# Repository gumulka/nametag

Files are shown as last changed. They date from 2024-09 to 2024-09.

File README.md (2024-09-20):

# Bluetooth ePaper Nametag

A simle project to show my name on an e-Paper

## How to build

If you are new to Zephyr, read the [Getting Started Guide](https://docs.zephyrproject.org/latest/develop/getting_started/index.html).
Afterwards you can clone and build this project with:

```bash
west init -m https://github.com/gumulka/nametag --mr main nametag
cd nametag
west update
cd epaper_nametag
```

### Bootloader

The bootloader will load and verify the image that is executed. To make it
easier to upgrade the device, two images are saved on the device and only one is
being executed, while the other is a standby for updating. The bootloader cannot
be upgraded via ble, but the image can be. Therefore making it possible to
upgrade devices in the field.

If you have a unprogrammed device, use this to build and flash the bootloader:

```bash
west build -p -b epaper_nametag -d build_mcuboot ../bootloader/mcuboot/boot/zephyr/ -- -DCONFIG_BOOT_SIGNATURE_TYPE_ECDSA_P256=y
west flash -d build_mcuboot
```

### Application

The application is different from the bootloader and is what is in need of
updates/upgrades.

```bash
west build -p -b epaper_nametag app -- -DOVERLAY_CONFIG="output.conf"
west flash
```

## Update via BLE

If you have an already running device and just want to upgrade to the latest
firmware.

Either with the nRF Connect App, which can be quite handy, or in the commandline
use these steps:

```bash
sudo mcumgr --conntype ble --connstring ctlr_name=hci0,peer_name='Nametag' image upload build/zephyr/zephyr.signed.bin
sudo mcumgr --conntype ble --connstring ctlr_name=hci0,peer_name='Nametag' image list
```

Use the second hash provided from the second command to alter the following:

```bash
sudo mcumgr --conntype ble --connstring ctlr_name=hci0,peer_name='Nametag' image test "HASH_FROM_OUTPUT"
sudo mcumgr --conntype ble --connstring ctlr_name=hci0,peer_name='Nametag' reset
# wait for the system to restart and if you are sure, that the update was successful then
sudo mcumgr  --conntype ble --connstring ctlr_name=hci0,peer_name='Nametag' image confirm "HASH_FROM_OUTPUT"
```

More information about the general procedure can be found [here](https://docs.zephyrproject.org/latest/samples/subsys/mgmt/mcumgr/smp_svr/README.html)
and [here](https://docs.zephyrproject.org/latest/services/device_mgmt/mcumgr.html)

> [!TIP]
> I have seen a few errors when trying to upload the image and found that it
> works best, if I cancel the upload command after a few seconds and restart it
> a few seconds later, basically splitting the upload into 4-5 chunks instead
> of uploading it as a whole.

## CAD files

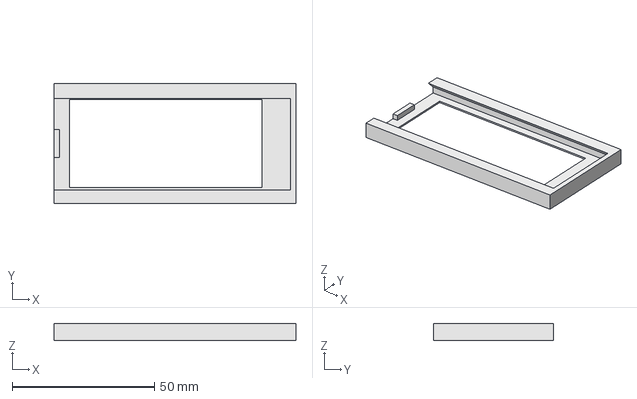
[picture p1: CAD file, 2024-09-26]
Case/Case.FCStd
85.0 x 42.0 x 6.00 mm

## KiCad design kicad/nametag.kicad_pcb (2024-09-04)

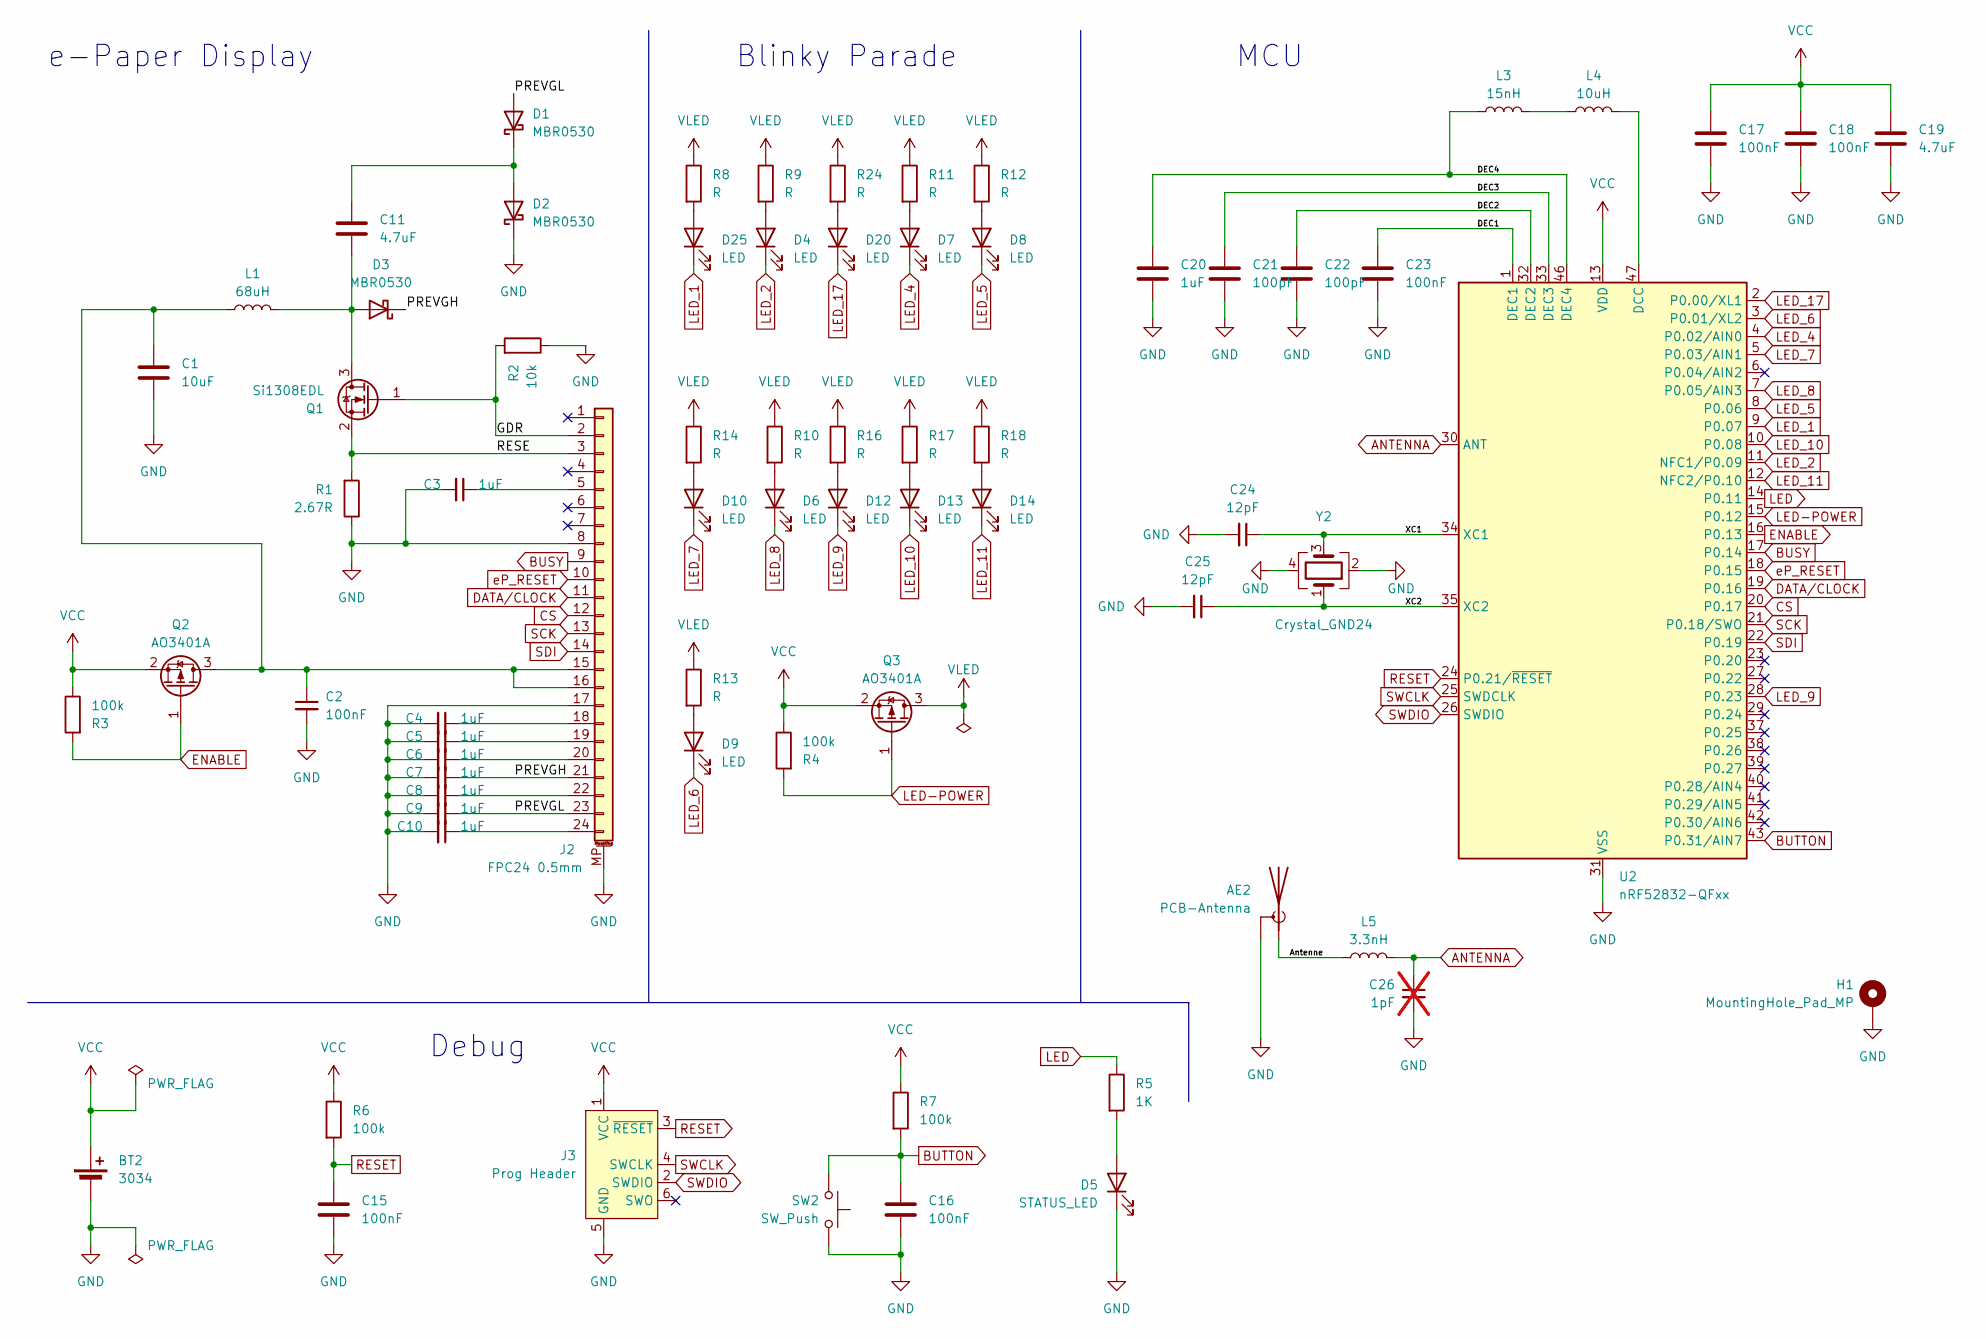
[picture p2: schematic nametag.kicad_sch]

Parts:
AE2: PCB-Antenna; Texas_SWRA117D_2.4GHz_Right
BT2: 3034; BatteryHolder_Keystone_3034_1x20mm; MPN 3034TR; LCSC# C5213768
C1: 10uF; C_0603_1608Metric
C2: 100nF; C_0402_1005Metric
C3, C4, C5, C6, C7, C8, C9, C10: 1uF; C_0603_1608Metric
C11: 4.7uF; C_0603_1608Metric
C15, C16, C17, C18, C23: 100nF; C_0402_1005Metric; MPN 100nF 0402; LCSC# C1525
C19: 4.7uF; C_0603_1608Metric; MPN 4,7uF 0603; LCSC# C19666
C20: 1uF; C_0603_1608Metric; MPN 1uF 0603; LCSC# C15849
C21, C22: 100pF; C_0402_1005Metric; MPN 100pF 0402; LCSC# C1546
C24, C25: 12pF; C_0402_1005Metric; MPN 12pF 0402; LCSC# C1547
C26: 1pF; C_0402_1005Metric; not fitted
D1, D2, D3: MBR0530; D_SOD-123
D4, D6, D7, D8, D9, D10, D12, D13, D14, D20, D25: LED; LTST-C230
D5: STATUS_LED; LED_0603_1608Metric; MPN KP-1608SGC; LCSC# C72043
H1: MountingHole_Pad_MP; Safety-pin
J2: FPC24 0.5mm; AMPHENOL_SFV24R-4STBE1HLF
J3: Prog Header; Tag-Connect_TC2030-IDC-NL_2x03_P1.27mm_Vertical
L1: 68uH; L_1210_3225Metric
L3: 15nH; L_0402_1005Metric; MPN LQW15AN15NH00D; LCSC# C27143
L4: 10uH; L_0603_1608Metric; MPN MLZ1608E100MT; LCSC# C1035
L5: 3.3nH; L_0402_1005Metric; MPN LQG15HS3N3C02D; LCSC# C14033
Q1: Si1308EDL; SOT-323_SC-70
Q2, Q3: AO3401A; SOT-23
R1: 2.67R; R_0603_1608Metric
R2: 10k; R_0603_1608Metric
R3, R4: 100k; R_0603_1608Metric
R5: 1K; R_0603_1608Metric; MPN 1K; LCSC# C11702
R6, R7: 100k; R_0603_1608Metric; MPN 100K; LCSC# C25741
R8, R9, R10, R11, R12, R13, R14, R16, R17, R18, R24: R; R_0603_1608Metric
SW2: SW_Push; SW_SPST_TL3342; MPN TS-1187A-B-A-B; LCSC# C318884
U2: nRF52832-QFxx; QFN-48-1EP_6x6mm_P0.4mm_EP4.6x4.6mm; MPN NRF52832-QFAA-R; LCSC# C77540
Y2: Crystal_GND24; Crystal_SMD_3225-4Pin_3.2x2.5mm; MPN X322532MOB4SI; LCSC# C9009

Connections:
/Antenne: AE2.1 (A), L5.2
/DEC1: C23.1, U2.1 (DEC1)
/DEC2: C22.1, U2.32 (DEC2)
/DEC3: C21.1, U2.33 (DEC3)
/DEC4: C20.1, L3.1, U2.46 (DEC4)
/GDR: J2.2, Q1.1 (G), R2.2
/PREVGH: C7.1, D3.1 (K), J2.21
/PREVGL: C9.1, D1.2 (A), J2.23
/RESE: J2.3, Q1.2 (S), R1.2
/XC1: C24.1, U2.34 (XC1), Y2.3
/XC2: C25.1, U2.35 (XC2), Y2.1
ANTENNA: C26.1, L5.1, U2.30 (ANT)
BUSY: J2.9, U2.17 (P0.14)
BUTTON: C16.1, R7.2, SW2.2, U2.43 (P0.31/AIN7)
CS: J2.12, U2.20 (P0.17)
DATA/CLOCK: J2.11, U2.19 (P0.16)
ENABLE: Q2.1 (G), R3.2, U2.16 (P0.13)
GND: AE2.2 (Shield), BT2.2 (-), C1.2, C2.2, C3.2, C4.2, C5.2, C6.2, C7.2, C8.2, C9.2, C10.2, C15.2, C16.2, C17.2, C18.2, C19.2, C20.2, C21.2, C22.2, C23.2, C24.2, C25.2, C26.2, D2.1 (K), D5.1 (K), H1.MP, J2.8, J2.17, J2.MP (MountPin), J3.5 (GND), R1.1, R2.1, SW2.1, U2.31 (VSS), U2.45 (VSS), U2.49 (VSS), Y2.2, Y2.4
LED: R5.1, U2.14 (P0.11)
LED-POWER: Q3.1 (G), R4.2, U2.15 (P0.12)
LED_1: D25.1 (K), U2.9 (P0.07)
LED_2: D4.1 (K), U2.11 (NFC1/P0.09)
LED_4: D7.1 (K), U2.4 (P0.02/AIN0)
LED_5: D8.1 (K), U2.8 (P0.06)
LED_6: D9.1 (K), U2.3 (P0.01/XL2)
LED_7: D10.1 (K), U2.5 (P0.03/AIN1)
LED_8: D6.1 (K), U2.7 (P0.05/AIN3)
LED_9: D12.1 (K), U2.28 (P0.23)
LED_10: D13.1 (K), U2.10 (P0.08)
LED_11: D14.1 (K), U2.12 (NFC2/P0.10)
LED_17: D20.1 (K), U2.2 (P0.00/XL1)
unnamed: C11.1, D1.1 (K), D2.2 (A)
unnamed: C11.2, D3.2 (A), L1.1, Q1.3 (D)
unnamed: D4.2 (A), R9.2
unnamed: D5.2 (A), R5.2
unnamed: D6.2 (A), R10.2
unnamed: D7.2 (A), R11.2
unnamed: D8.2 (A), R12.2
unnamed: D9.2 (A), R13.2
unnamed: D10.2 (A), R14.2
unnamed: D12.2 (A), R16.2
unnamed: D13.2 (A), R17.2
unnamed: D14.2 (A), R18.2
unnamed: D20.2 (A), R24.2
unnamed: D25.2 (A), R8.2
unnamed: C3.1, J2.5
unnamed: C1.1, C2.1, J2.15, J2.16, L1.2, Q2.3 (D)
unnamed: C4.1, J2.18
unnamed: C5.1, J2.19
unnamed: C6.1, J2.20
unnamed: C8.1, J2.22
unnamed: C10.1, J2.24
unnamed: L3.2, L4.1
unnamed: L4.2, U2.47 (DCC)
RESET: C15.1, J3.3 (~RESET), R6.2, U2.24 (P0.21/~RESET)
SCK: J2.13, U2.21 (P0.18/SWO)
SDI: J2.14, U2.22 (P0.19)
SWCLK: J3.4 (SWCLK), U2.25 (SWDCLK)
SWDIO: J3.2 (SWDIO), U2.26 (SWDIO)
VCC: BT2.1 (+), C17.1, C18.1, C19.1, J3.1 (VCC), Q2.2 (S), Q3.2 (S), R3.1, R4.1, R6.1, R7.1, U2.13 (VDD), U2.36 (VDD), U2.48 (VDD)
VLED: Q3.3 (D), R8.1, R9.1, R10.1, R11.1, R12.1, R13.1, R14.1, R16.1, R17.1, R18.1, R24.1
eP_RESET: J2.10, U2.18 (P0.15)

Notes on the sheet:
e-Paper Display
Blinky Parade
Debug
MCU

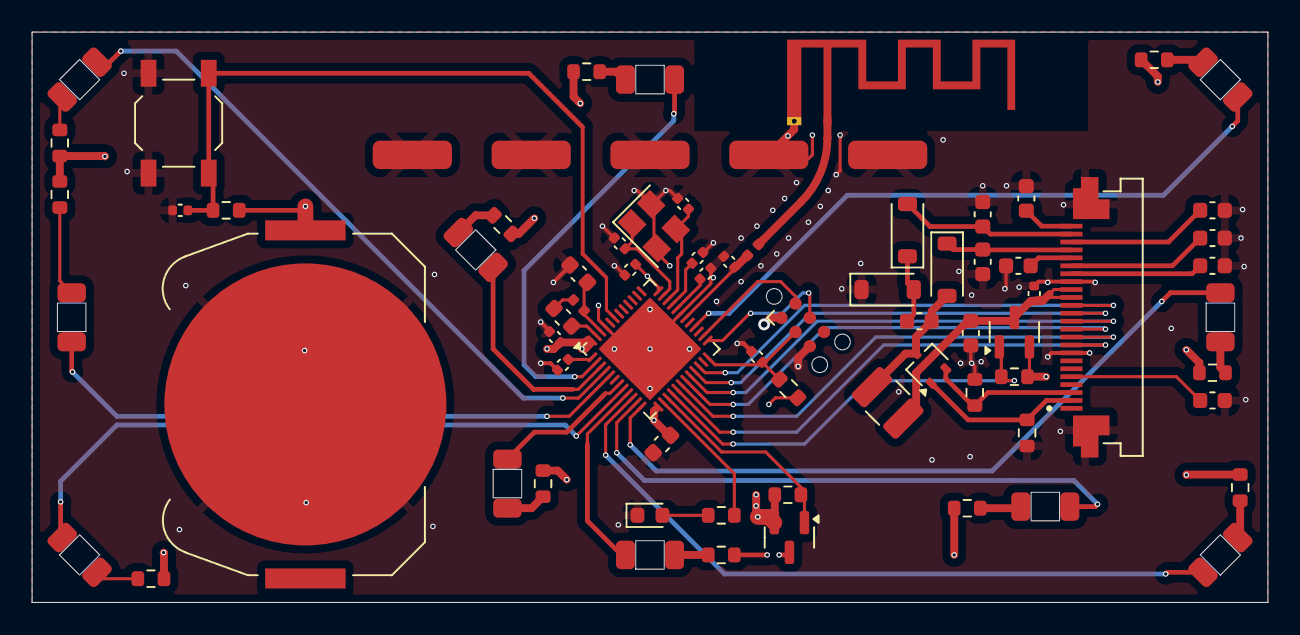
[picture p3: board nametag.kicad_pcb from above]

Board: 4 copper layers, 78.0 x 36.0 mm, 71 parts (0 on the bottom side), 62 nets.

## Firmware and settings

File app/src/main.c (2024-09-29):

#include <zephyr/kernel.h>
#include <zephyr/drivers/gpio.h>
#include <zephyr/display/cfb.h>

#include "nametag.h"

#include <zephyr/logging/log.h>
LOG_MODULE_REGISTER(main, CONFIG_APP_LOG_LEVEL);

static const struct gpio_dt_spec led = GPIO_DT_SPEC_GET(DT_ALIAS(led0), gpios);
static const struct gpio_dt_spec button = GPIO_DT_SPEC_GET_OR(DT_ALIAS(sw0), gpios, {0});
static struct gpio_callback button_cb_data;

static const struct device *const display = DEVICE_DT_GET(DT_CHOSEN(zephyr_display));

static int current_image = 0;

typedef int (*image_display)(const struct device *const display);

image_display images[10] = {
	serious_name, serious_nick,     serious_full_name,
	lgbtq_name,   lgbtq_name_extra, fabilicious_turtli,
};

static void set_display(struct k_work *_work)
{
	clear_display(display);
	if (current_image < ARRAY_SIZE(images) && images[current_image]) {
		images[current_image](display);
	} else {
		current_image = -1;
	}
}
K_WORK_DELAYABLE_DEFINE(set_display_work, set_display);

void button_pressed(const struct device *dev, struct gpio_callback *cb, uint32_t pins)
{
	printk("Button pressed at %" PRIu32 "\n", k_cycle_get_32());
	current_image++;
	k_work_reschedule(&set_display_work, K_MSEC(1000));
}

int main(void)
{
	int ret;

	if (!gpio_is_ready_dt(&led)) {
		LOG_ERR("No LED defined");
		return -ENODEV;
	}

	ret = gpio_pin_configure_dt(&led, GPIO_OUTPUT_INACTIVE);
	if (ret < 0) {
		LOG_ERR("Could not configure LED.");
		return 0;
	}

	if (!device_is_ready(display)) {
		LOG_WRN("Display device not ready");
		return -ENODEV;
	}

	ret = cfb_framebuffer_init(display);
	if (ret) {
		LOG_WRN("Framebuffer initialization failed!");
		return ret;
	}

	if (!gpio_is_ready_dt(&button)) {
		printk("Error: button device %s is not ready\n", button.port->name);
		return -ENODEV;
	}

	ret = gpio_pin_configure_dt(&button, GPIO_INPUT);
	if (ret != 0) {
		printk("Error %d: failed to configure %s pin %d\n", ret, button.port->name,
		       button.pin);
		return 0;
	}

	ret = gpio_pin_interrupt_configure_dt(&button, GPIO_INT_EDGE_TO_ACTIVE);
	if (ret != 0) {
		printk("Error %d: failed to configure interrupt on %s pin %d\n", ret,
		       button.port->name, button.pin);
		return 0;
	}

	gpio_init_callback(&button_cb_data, button_pressed, BIT(button.pin));
	gpio_add_callback(button.port, &button_cb_data);

	k_work_reschedule(&set_display_work, K_MSEC(1000));

	return 0;
}

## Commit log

2024-08-28 Started to work on a nametag
    I want to have a bluetooth controlled e-paper nametag.
    And the ESP32 seems to be a bit to power hungry, but working with
    BLE and a nRF52832 might be just power efficient enough to work for a
    long time.
    [nametag.kicad_pcb, nametag.kicad_sch]
2024-09-03 First routing
    Did the routing for everything and made it somewhat useable.
    Have to sleep again for a night to see if I want to do it like this.
    [nametag.kicad_pcb, nametag.kicad_sch]
2024-09-03 Add Schematic for Waveshare ESP32 controller
    The board was hte inspiration and background for the schematic part of
    the e-paper controller.
2024-09-04 Last changes before ordering
    [nametag.kicad_pcb]
2024-09-13 Add basic zephyr firmware
    Not more then the blinky sample, but a working blinky sample
    nonetheless :)
2024-09-26 Add devicetree definition for e-Paper
    Tested the somewhat working code with the display example.
    But only add now the definitions of how to access the e-paper by
    looking at the code from waveshare and seeing on how to adapt it to the
    driver.
2024-09-26 Added 3D modeled case
    Modeled in FreeCad for a basic Case to support the device and display
    [Case.FCStd]
2024-09-29 Iterate through screens with button
    Changing the screens on button press instead of a timer allows better
    control.
